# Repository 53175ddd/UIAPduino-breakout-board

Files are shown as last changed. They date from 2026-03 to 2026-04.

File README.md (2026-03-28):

# UIAPduino Breakout Board

UIAPduino を使った開発を手助けする，ブレッドボード用のブレイクアウトボードです．

## 部品表

| 部品番号 | 部品名 | 定数等 | リンク |
|----|----|----|----|
| C1 | コンデンサ | 0.22uF | [108146](<https://akizukidenshi.com/catalog/g/g108146/>) |
| C2 | コンデンサ | 0.1uF | [110147](<https://akizukidenshi.com/catalog/g/g110147/>) |
| C3 | コンデンサ | 22uF | [117899](<https://akizukidenshi.com/catalog/g/g117899/>) |
| C4 | コンデンサ | 10uF | [110590](<https://akizukidenshi.com/catalog/g/g110590/>) |
| D1 | ダイオード | 1N4148 | [100941](<https://akizukidenshi.com/catalog/g/g100941/>) |
| J1 | ピンヘッダ | 20P | [116590](<https://akizukidenshi.com/catalog/g/g116590/>) |
| J2 | ピンソケット | 20P | [103077](<https://akizukidenshi.com/catalog/g/g103077/>) |
| J3 | DC ジャック | 55-25 | [106568](<https://akizukidenshi.com/catalog/g/g106568/>) |
| U1 | USB-UART 変換 | FT234X モジュール | [108461](<https://akizukidenshi.com/catalog/g/g108461/>) |
| U2 | マイコン | UIAPduino Pro Micro CH32V003 | [ssci.to/9914](<https://www.switch-science.com/products/9914>) |
| U3 | 電源レギュレータ | NJM7805 | [108678](<https://akizukidenshi.com/catalog/g/g108678/>) |

## アートワークイメージ

[KiCanvas](https://kicanvas.org) でアートワークを見ることができます．  
<https://kicanvas.org/?repo=https%3A%2F%2Fgithub.com%2F53175ddd%2FUIAPduino-breakout-board>

---

This work is licensed under <a href="https://creativecommons.org/licenses/by-sa/4.0/">CC BY-SA 4.0</a>

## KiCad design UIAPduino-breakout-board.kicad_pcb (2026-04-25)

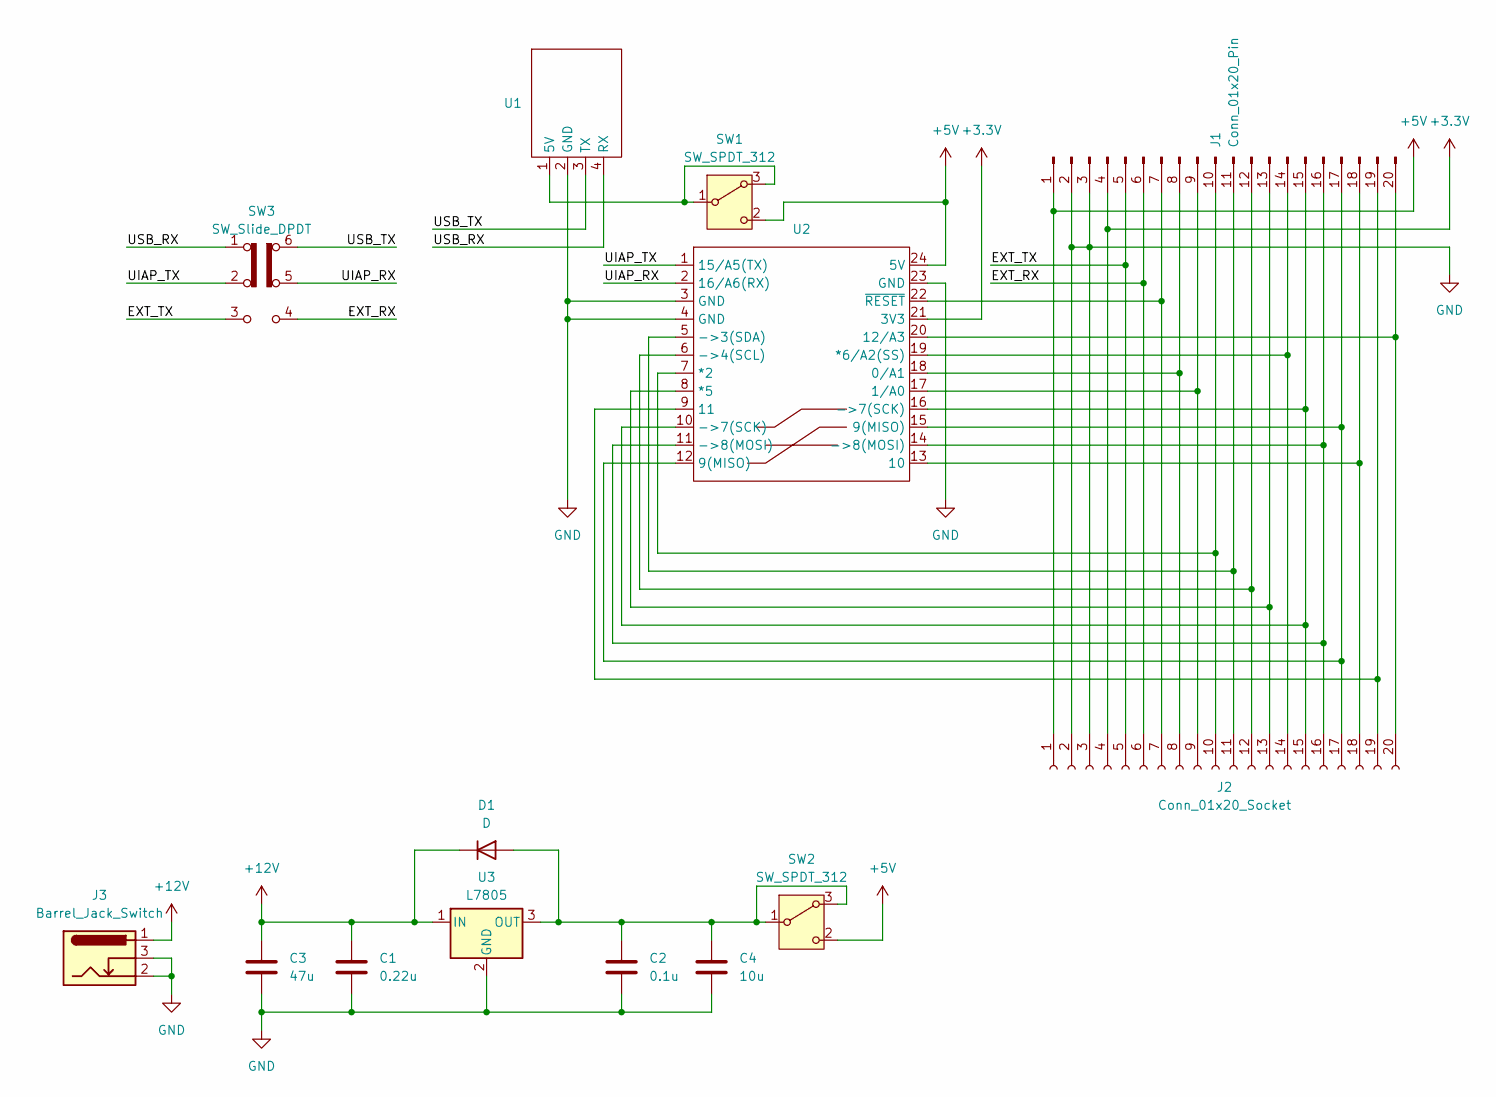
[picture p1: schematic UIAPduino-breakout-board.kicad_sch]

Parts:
C1: 0.22u; C_Disc_D5.0mm_W2.5mm_P5.00mm
C2: 0.1u; C_Disc_D5.0mm_W2.5mm_P5.00mm
C3: 47u; CP_Radial_D5.0mm_P2.00mm
C4: 10u; CP_Radial_D4.0mm_P1.50mm
D1: D; D_A-405_P7.62mm_Horizontal
J1: Conn_01x20_Pin; PinHeader_1x20_P2.54mm_Vertical
J2: Conn_01x20_Socket; PinSocket_1x20_P2.54mm_Vertical
J3: Barrel_Jack_Switch; BarrelJack_Horizontal
SW1, SW2: SW_SPDT_312; SW_Slide-03_Wuerth-WS-SLTV_10x2.5x6.4_P2.54mm
SW3: SW_Slide_DPDT; SW_CK_JS202011CQN_DPDT_Straight
U1: FT234X
U2: UIAPDUINO-PRO-MICRO-CH32V003-V1DOT4
U3: L7805; TO-220F-3_Vertical

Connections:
+3.3V: J1.4, J2.4, U2.21 (3V3)
+5V: J1.1, J2.1, SW1.2 (C), SW2.2 (C), U2.24 (5V)
+12V: C1.1, C3.1, D1.1 (K), J3.1, U3.1 (IN)
/EXT_RX: J1.6, J2.6, SW3.4 (A)
/EXT_TX: J1.5, J2.5, SW3.3 (C)
/UIAP_RX: SW3.5 (B), U2.2 (16/A6(RX))
/UIAP_TX: SW3.2 (B), U2.1 (15/A5(TX))
/USB_RX: SW3.1 (A), U1.4 (RX)
/USB_TX: SW3.6 (C), U1.3 (TX)
GND: C1.2, C2.2, C3.2, C4.2, J1.2, J1.3, J2.2, J2.3, J3.2, J3.3, U1.2 (GND), U2.3 (GND), U2.4 (GND), U2.23 (GND), U3.2 (GND)
unnamed: C2.1, C4.1, D1.2 (A), SW2.1 (B), SW2.3 (A), U3.3 (OUT)
unnamed: J1.7, J2.7, U2.22 (~RESET)
unnamed: J1.8, J2.8, U2.18 (0/A1)
unnamed: J1.9, J2.9, U2.17 (1/A0)
unnamed: J1.10, J2.10, U2.7 (*2)
unnamed: J1.11, J2.11, U2.5 (->3(SDA))
unnamed: J1.12, J2.12, U2.6 (->4(SCL))
unnamed: J1.13, J2.13, U2.8 (*5)
unnamed: J1.14, J2.14, U2.19 (*6/A2(SS))
unnamed: J1.15, J2.15, U2.10 (->7(SCK)), U2.16 (->7(SCK))
unnamed: J1.16, J2.16, U2.11 (->8(MOSI)), U2.14 (->8(MOSI))
unnamed: J1.17, J2.17, U2.12 (9(MISO)), U2.15 (9(MISO))
unnamed: J1.18, J2.18, U2.13 (10)
unnamed: J1.19, J2.19, U2.9 (11)
unnamed: J1.20, J2.20, U2.20 (12/A3)
unnamed: SW1.1 (B), SW1.3 (A), U1.1 (5V)

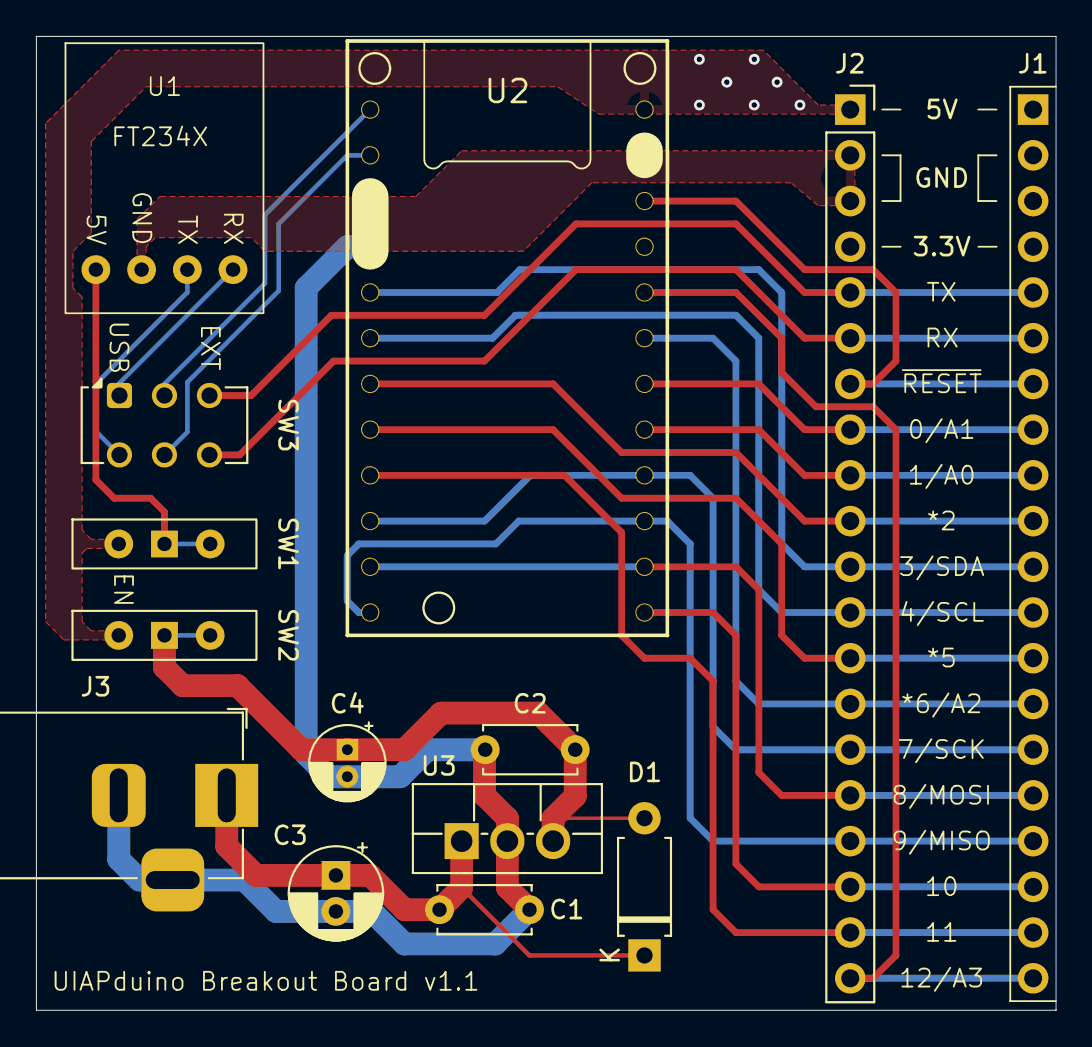
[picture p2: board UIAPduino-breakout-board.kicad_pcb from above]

Board: 2 copper layers, 56.6 x 54.1 mm, 14 parts (1 on the bottom side), 26 nets.

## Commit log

2026-02-19 kicad pj
    [UIAPduino-breakout-board.kicad_pcb, UIAPduino-breakout-board.kicad_sch]
2026-02-19 UIAPduino の sym と fp
2026-02-19 USB シリアル変換器
2026-02-19 FP 割り当て
    [UIAPduino-breakout-board.kicad_sch]
2026-02-19 大まかな配置
    [UIAPduino-breakout-board.kicad_pcb]
2026-02-19 回路修正
    [UIAPduino-breakout-board.kicad_sch]
2026-02-19 信号線を配線
    [UIAPduino-breakout-board.kicad_pcb]
2026-02-19 電源配置を変更
    [UIAPduino-breakout-board.kicad_pcb, UIAPduino-breakout-board.kicad_sch]
2026-02-19 配線をいい感じに
    [UIAPduino-breakout-board.kicad_pcb]
2026-02-19 だいたい仕上げた
    [UIAPduino-breakout-board.kicad_pcb]
2026-02-19 電源入力回路追加
    [UIAPduino-breakout-board.kicad_sch]
2026-02-19 JP の向きを反転
    [UIAPduino-breakout-board.kicad_pcb, UIAPduino-breakout-board.kicad_sch]
2026-02-19 7805 の FP 変更
    [UIAPduino-breakout-board.kicad_sch]
2026-02-19 電源回路追加
    [UIAPduino-breakout-board.kicad_pcb]
2026-02-19 外形とシルクを調整
    [UIAPduino-breakout-board.kicad_pcb]
2026-02-19 readme に部品表を追加
2026-02-22 パターン修正
    [UIAPduino-breakout-board.kicad_pcb]
2026-02-22 製造データ出力
    [UIAPduino-breakout-board.kicad_pcb]
2026-03-02 地味改良
    [UIAPduino-breakout-board.kicad_pcb]
2026-03-03 基板外形調整
    [UIAPduino-breakout-board.kicad_pcb]
2026-03-03 ベタ塗り直し
    [UIAPduino-breakout-board.kicad_pcb]
2026-03-14 ジャンパをスイッチに変更
    [UIAPduino-breakout-board.kicad_pcb, UIAPduino-breakout-board.kicad_sch]
2026-03-14 なくていい配線を削除
    [UIAPduino-breakout-board.kicad_pcb]
2026-03-14 UART 接続先切り替え用スイッチを追加
    [UIAPduino-breakout-board.kicad_pcb, UIAPduino-breakout-board.kicad_sch]
2026-03-14 電源配線ちょい弄り
    [UIAPduino-breakout-board.kicad_pcb]
2026-03-14 シルク調整
    [UIAPduino-breakout-board.kicad_pcb]
2026-03-14 3.3V の引出し線の調整
    [UIAPduino-breakout-board.kicad_pcb]
2026-03-14 ベタの形が気に食わん
    [UIAPduino-breakout-board.kicad_pcb]
2026-03-22 配線を見直して via を除去
    [UIAPduino-breakout-board.kicad_pcb]
2026-03-22 配線修正
    [UIAPduino-breakout-board.kicad_pcb, UIAPduino-breakout-board.kicad_sch]
2026-03-22 なくしてた接続を戻した
    [UIAPduino-breakout-board.kicad_pcb]
2026-03-25 シルク印刷の調整
    [UIAPduino-breakout-board.kicad_pcb]
2026-03-25 余計な迂回を解消
    [UIAPduino-breakout-board.kicad_pcb]
2026-04-04 微妙な配線修正
    [UIAPduino-breakout-board.kicad_pcb]
2026-04-25 5V 部分をちょっと変更
    [UIAPduino-breakout-board.kicad_pcb]
